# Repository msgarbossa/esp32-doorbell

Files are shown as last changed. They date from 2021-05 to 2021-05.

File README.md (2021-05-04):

# ESP32 doorbell

## Description

My doorbell chime stopped working so I made my own smart doorbell.

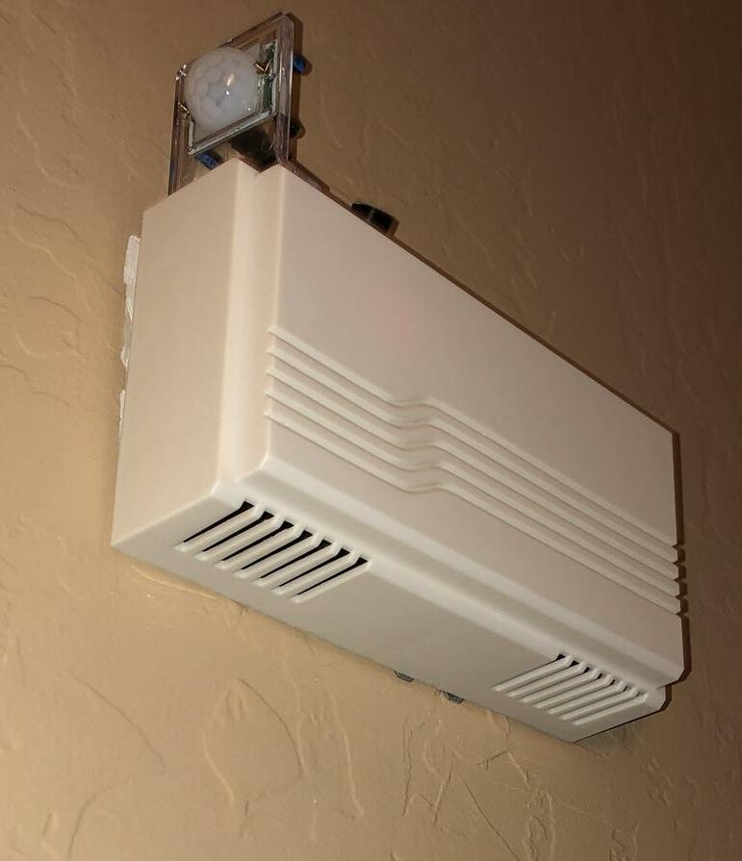
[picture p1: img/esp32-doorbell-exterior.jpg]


- Drop-in replacement for existing doorbell
- Uses original low-tech button
- NTP is used to set time and allow for Do-not-Disturb hours
- In addition to playing a sound when the doorbell button is pressed, an MQTT message is published
- A PIR motion sensor also sends MQTT messages
- Node-RED subscribes to the MQTT topic and sends a message using Slack when the doorbell button is pressed
- Node-RED publishes Prometheus metrics so events can be graphed in Grafana

## Parts

- [ESP32 devkit - 30 pin, integrated antenna](https://www.aliexpress.com/item/1005001267643044.html)
- [passive piezo buzzer](https://www.aliexpress.com/item/4001317667682.html) or anything to make noise
- [HC-SR501 Infrared PIR Motion Sensor](https://www.aliexpress.com/item/32731348914.html)

## Code

As my first major rewrite of my doorbell, I originally changed everything to attach interrupts to the digital input pins for the doorbell button and motion sensor.  Unfortunately, this was not reliable and caused too many false alarms.  I'm pretty sure the long telephone wire that runs from the doorbell to the door was picking up elecrical noise and acting like a large antenna.  I may eventually purchase some octocouplers and try this out again.  The working code is back to a more traditional setup of polling and reading the digital inputs.  Going with interrupts would also allow deep sleep to be used.

## Assembly

The inside is a bit ugly.  I gutted the box with a dremel tool and a cutoff wheel.  I removed the old transformer from the wall and replaced it with a standard receptacle.  The small USB adapter has the port on the side, allowing the existing doorbell cover to fit over all of the parts.  I was considering 3D printing a 2-gang electrical box cover to completely replace the old doorbell case, but I'd have some paint to touch up and I just started learning FreeCAD and wanted to start small.

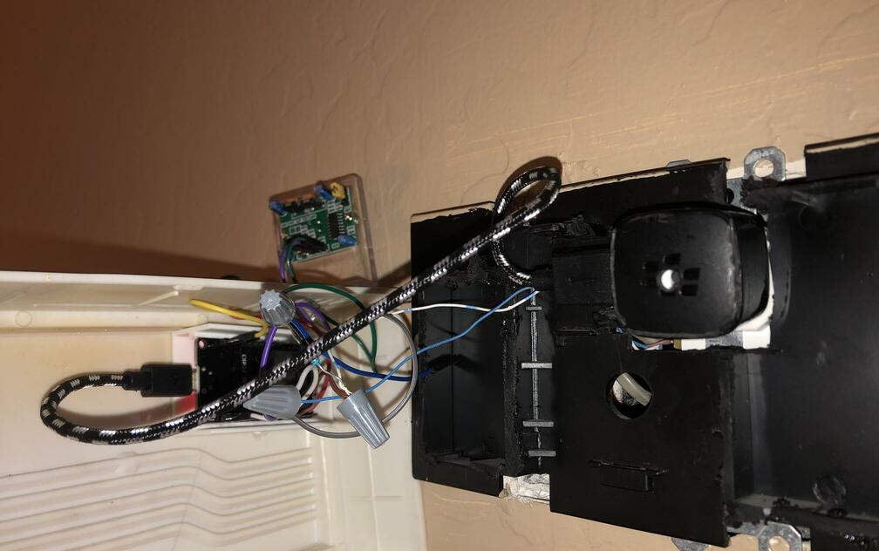
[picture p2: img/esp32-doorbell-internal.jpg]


The FreeCAD and STL files are in the *case* folder.  The rails perfectly fit the 30-pin ESP32 w/ integrated antenna and the 38-pin ESP32 w/ external antenna.  This was my first test-print, but it helped with the assembly to quickly hot-glue the ESP32 holder to the inside of the old doorbell case.

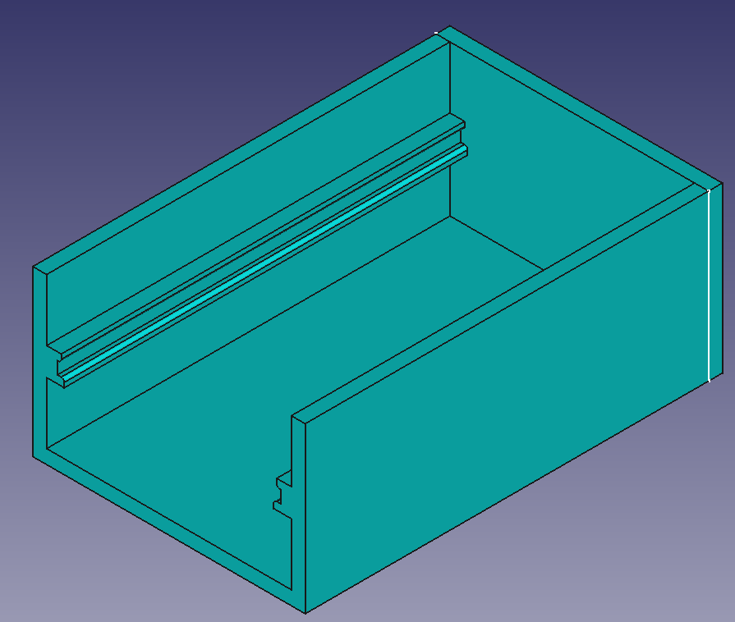
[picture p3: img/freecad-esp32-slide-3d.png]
3d-case-model


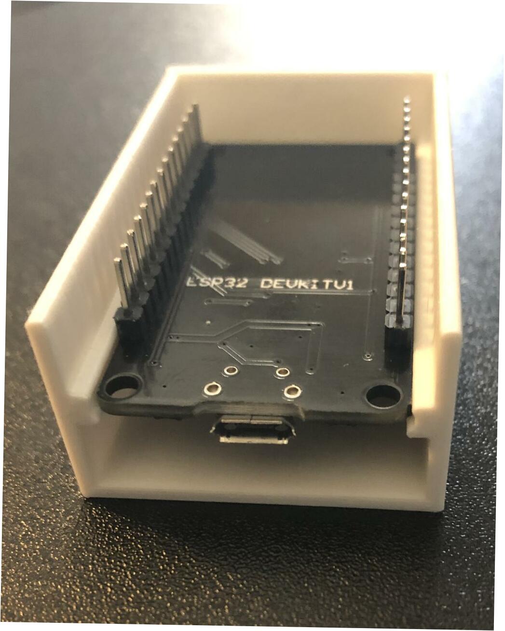
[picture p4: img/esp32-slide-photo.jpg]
project photo


## Diagram

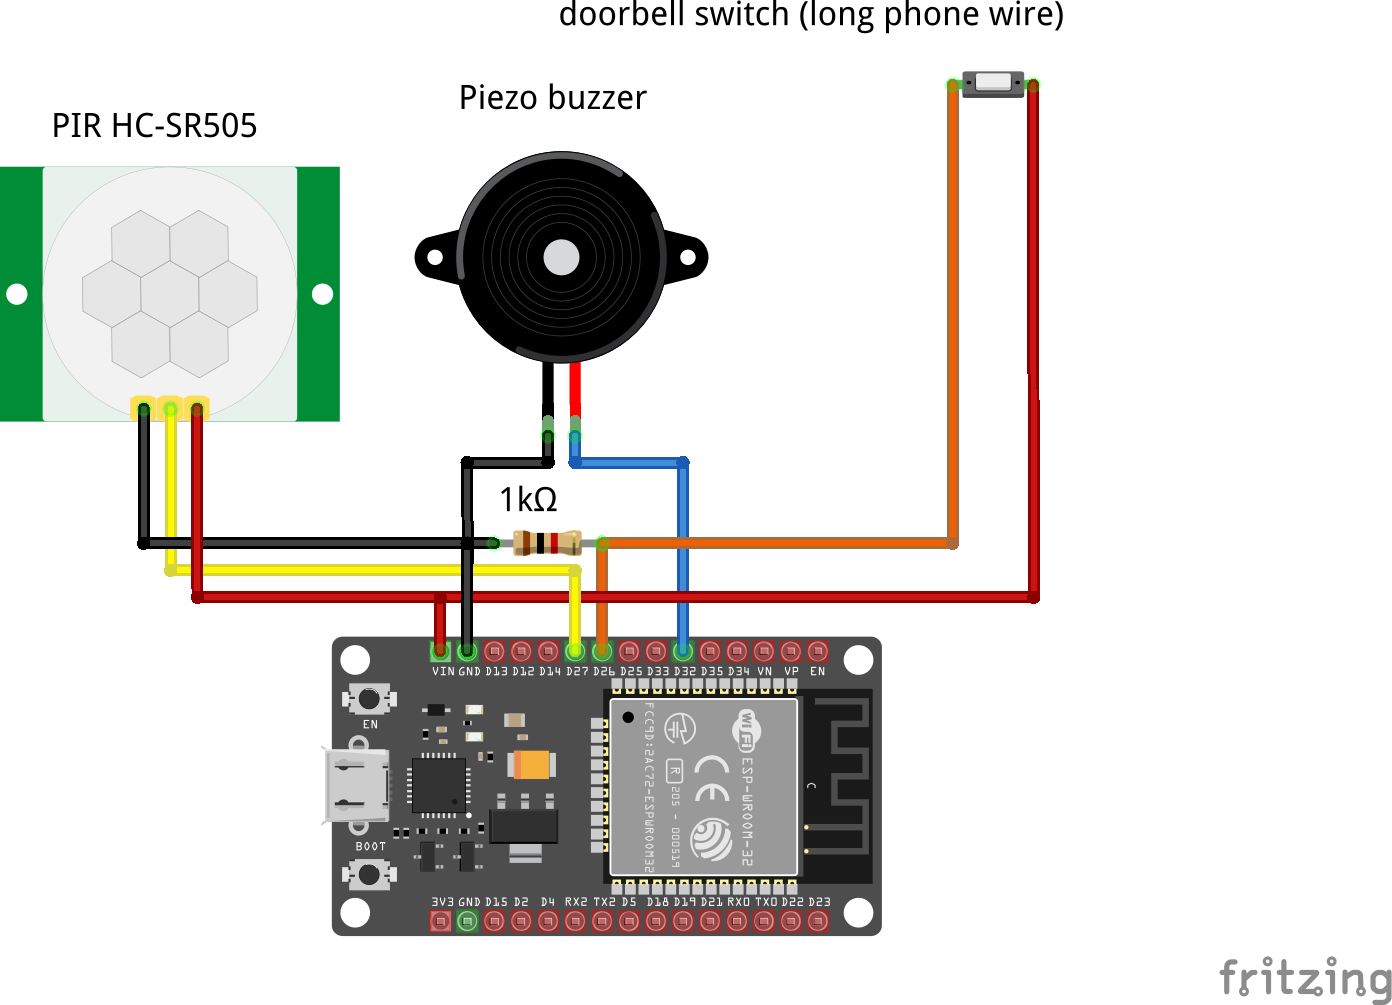
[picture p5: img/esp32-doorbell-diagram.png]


When developing this, I swapped the buzzer out for an LED with the same code.

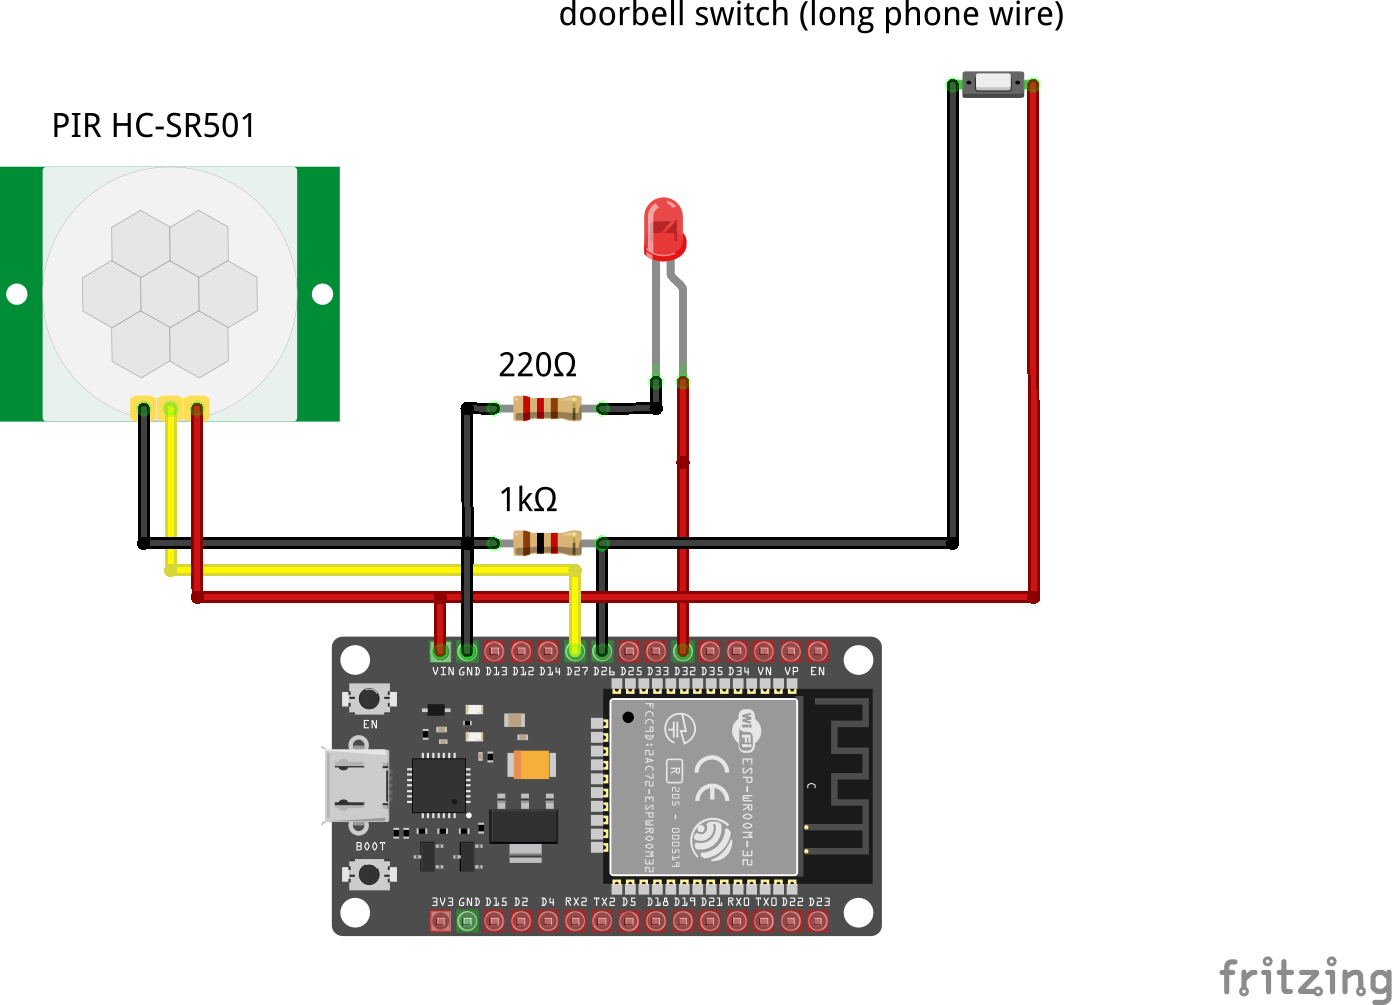
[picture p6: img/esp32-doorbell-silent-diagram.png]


## Node-RED

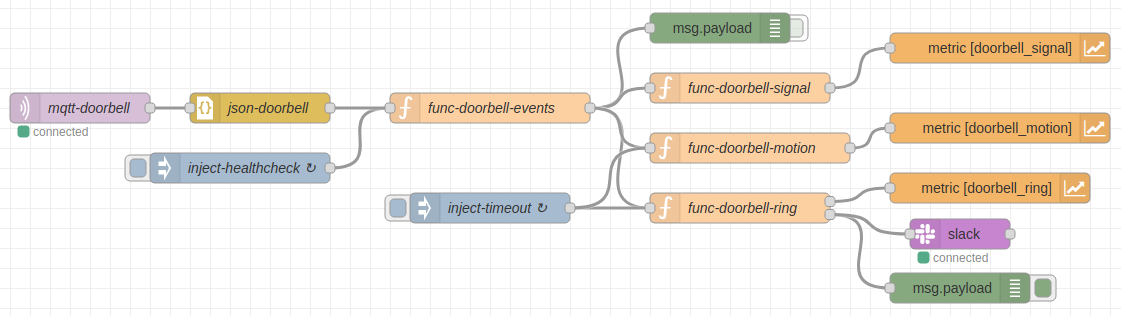
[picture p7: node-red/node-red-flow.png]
Node-RED flow

[JSON for above flow](node-red/flow.json)

The beginning of the flow starts out with Node-RED listening on the MQTT topic for messages.  The messages get converted from JSON to payload objects.  Whenever an MQTT message is received, a timestamp is recorded in the func-doorbell-events node.

The "inject healthcheck" node periodically sends a message that is compared to the last MQTT timestamp.  If no MQTT messages have been recieved for a while, the flow is marked offline and a new message is returned to zero out the Prometheus metrics at the end of the flow.

The "inject timeout" handles resetting the motion and doorbell Prometheus metrics back to zero after an alert, but ensures the value stays at "1" long enough for Prometheus to scrape the exporter.

The Prometheus data shown below is at \<node_red_url\>:1880/metrics.

```
# HELP doorbell_signal doorbell signal
# TYPE doorbell_signal gauge
doorbell_signal -59

# HELP doorbell_ring doorbell ring
# TYPE doorbell_ring gauge
doorbell_ring 0

# HELP doorbell_motion doorbell motion
# TYPE doorbell_motion gauge
doorbell_motion 0
```

The func-doorbell-ring node also sends a message to Slack.

Below is an example graph in Grafana.

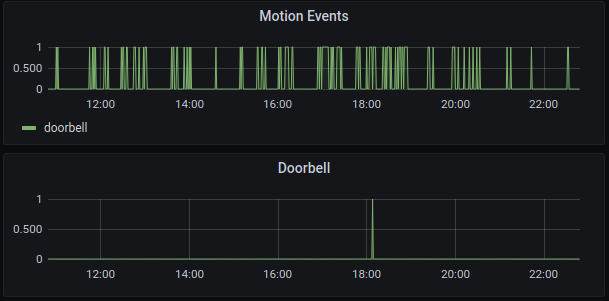
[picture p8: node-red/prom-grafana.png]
Prometheus - Grafana


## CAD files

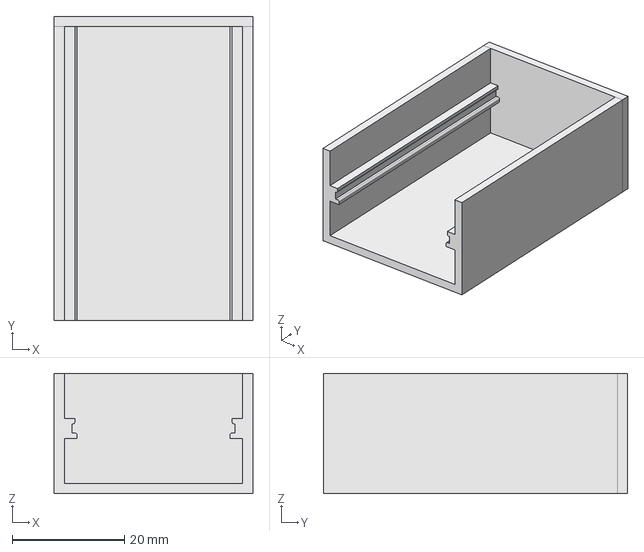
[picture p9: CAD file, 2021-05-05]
case/esp32-slide-case.step
35.4 x 54.2 x 21.4 mm

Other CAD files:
case/esp32-slide-case.stl

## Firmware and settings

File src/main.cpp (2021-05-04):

#include <Arduino.h>
#include <WiFi.h>
extern "C" {
  #include "freertos/FreeRTOS.h"
  #include "freertos/timers.h"
}
#include <AsyncMqttClient.h>
#include <time.h>

#include "config/config.h"
#include "functions/wifi-connection.h"
#include "functions/ota.h"
#include "functions/doorbell.h"
#include "functions/mqtt.h"
#include "functions/motion.h"

// #include "tasks/motion-detect.h"

#ifdef __arm__
// should use uinstd.h to define sbrk but Due causes a conflict
extern "C" char* sbrk(int incr);
#else  // __ARM__
extern char *__brkval;
#endif  // __arm__

// Variables to hold metric/sensor values
int doorbellStatus = 0;
bool doorbellChanged = false;
int motionState = 0;
bool motionChanged = false;
unsigned long prevMillisMotion = 0; // Stores last motionState = 1
unsigned long prevMillisDoorbell = 0;  // Stores last doorbellStatus = 1
unsigned long prevMillisMQTT = 0;   // Stores last time sensor was published
unsigned long prevNtpMillis = 0;   // Stores last time NTP was updated

// Variables to hold sensor info
int8_t wifi_strength;
IPAddress ip;
time_t now;
struct tm * timeinfo;
char TimeString[9]; // 8 digits plus the null char (00:00:00)


// Temperature MQTT Topics
#define MQTT_PUB_TOPIC "home/" DEVICE_NAME "/metrics"
#define MQTT_SUB_TOPIC "home/" DEVICE_NAME "/cmd"

AsyncMqttClient mqttClient;
TimerHandle_t mqttReconnectTimer;
TimerHandle_t wifiReconnectTimer;
// TimerHandle_t checkDoorTimer;
// TimerHandle_t checkLeakTimer;

const char* wl_status_to_string(int status) {
  switch (status) {
    case WL_NO_SHIELD: return "WL_NO_SHIELD";
    case WL_IDLE_STATUS: return "WL_IDLE_STATUS";
    case WL_NO_SSID_AVAIL: return "WL_NO_SSID_AVAIL";
    case WL_SCAN_COMPLETED: return "WL_SCAN_COMPLETED";
    case WL_CONNECTED: return "WL_CONNECTED";
    case WL_CONNECT_FAILED: return "WL_CONNECT_FAILED";
    case WL_CONNECTION_LOST: return "WL_CONNECTION_LOST";
    case WL_DISCONNECTED: return "WL_DISCONNECTED";
    default: return "UNKNOWN";
  }
}

void connectToWifi() {
  btStop(); // turn off bluetooth
  Serial.println("Connecting to Wi-Fi...");
  WiFi.begin(WIFI_NETWORK, WIFI_PASSWORD);
}

void connectToMqtt() {
  Serial.println("Connecting to MQTT...");
  mqttClient.connect();
}

void WiFiEvent(WiFiEvent_t event) {
  Serial.printf("[WiFi-event] event: %d\n", event);
  switch(event) {
    case SYSTEM_EVENT_STA_GOT_IP:
      Serial.println("WiFi connected");
      Serial.println("IP address: ");
      ip = WiFi.localIP();
      Serial.println(WiFi.localIP());
      connectToMqtt();
      break;
    case SYSTEM_EVENT_STA_DISCONNECTED:
      Serial.println("WiFi lost connection");
      xTimerStop(mqttReconnectTimer, 0); // ensure we don't reconnect to MQTT while reconnecting to Wi-Fi
      xTimerStart(wifiReconnectTimer, 0);
      break;
    default:
      break;
  }
}

void updateWiFiSignalStrength() {
  if(WiFi.isConnected()) {
    //serial_println(F("[WIFI] Updating signal strength..."));
    wifi_strength = WiFi.RSSI();
    // Serial.print("[WIFI] signal strength: ");
    // Serial.println(wifi_strength);
  }
}

void onMqttConnect(bool sessionPresent) {
  Serial.println("Connected to MQTT.");
  Serial.print("Session present: ");
  Serial.println(sessionPresent);
  uint16_t packetIdSub = mqttClient.subscribe(MQTT_SUB_TOPIC, 2);
  Serial.print("Subscribing at QoS 2, packetId: ");
  Serial.println(packetIdSub);
}

void onMqttDisconnect(AsyncMqttClientDisconnectReason reason) {
  Serial.println("Disconnected from MQTT.");
  if (WiFi.isConnected()) {
    xTimerStart(mqttReconnectTimer, 0);
  }
}

void onMqttPublish(uint16_t packetId) {
  Serial.print("Publish acknowledged.");
  Serial.print("  packetId: ");
  Serial.println(packetId);
}

void sendMqttUpdate() {
  char msg[58];  // variable for MQTT payload
  sprintf(msg, "{\"s\":\"%d\",\"d\":\"%d\",\"m\":\"%d\"}", wifi_strength, doorbellStatus, motionState);
  uint16_t packetIdPub1 = mqttClient.publish(MQTT_PUB_TOPIC, 0, false, msg);
  Serial.printf("[MQTT] Publishing on topic %s at QoS 1, packetId: %i\n", MQTT_PUB_TOPIC, packetIdPub1);
  Serial.println(msg);
}

void onMqttSubscribe(uint16_t packetId, uint8_t qos) {
  Serial.println("Subscribe acknowledged.");
  Serial.print("  packetId: ");
  Serial.println(packetId);
  Serial.print("  qos: ");
  Serial.println(qos);
}
void onMqttUnsubscribe(uint16_t packetId) {
  Serial.println("Unsubscribe acknowledged.");
  Serial.print("  packetId: ");
  Serial.println(packetId);
}

void onMqttMessage(char* topic, char* payload, AsyncMqttClientMessageProperties properties, size_t len, size_t index, size_t total) {
  Serial.println("Publish received.");
  Serial.print("  topic: ");
  Serial.println(topic);
  Serial.print("  qos: ");
  Serial.println(properties.qos);
  Serial.print("  dup: ");
  Serial.println(properties.dup);
  Serial.print("  retain: ");
  Serial.println(properties.retain);
  Serial.print("  len: ");
  Serial.println(len);
  Serial.print("  index: ");
  Serial.println(index);
  Serial.print("  total: ");
  Serial.println(total);

  char s_payload[len + 1];
  String payload2 = "";
  if (len < 20) {
    Serial.print("  payload: ");
    s_payload[len] = '\0';
    strncpy(s_payload, payload, len);
    Serial.println(s_payload);
    payload2 = s_payload;
  } else {
    Serial.println(" payload len>20");
  }
  if (payload2 == "blink") {
    blink_now();
    prevMillisMQTT = 0;
  }
  if (payload2 == "toggle") {
    play_sound();
  }

}


void fetchTimeFromNTP() {
  if(!WiFi.isConnected()) {
      return;
  }
  Serial.println("[NTP] Updating...");
  // init and get the time
  configTime(NTP_GMT_OFFSET_SECONDS, NTP_DAYLIGHT_OFFSET_SECONDS, NTP_SERVER);
  Serial.println("[NTP] Done");
}

void setup() {
  Serial.begin(115200);
  Serial.println();

  pinMode(LED_PIN, OUTPUT);  // Initialize the LED pin as an output

  // sound setup
  setup_sound();

  mqttReconnectTimer = xTimerCreate("mqttTimer", pdMS_TO_TICKS(2000), pdFALSE, (void*)0, reinterpret_cast<TimerCallbackFunction_t>(connectToMqtt));
  wifiReconnectTimer = xTimerCreate("wifiTimer", pdMS_TO_TICKS(2000), pdFALSE, (void*)0, reinterpret_cast<TimerCallbackFunction_t>(connectToWifi));

  WiFi.onEvent(WiFiEvent);

  mqttClient.onConnect(onMqttConnect);
  mqttClient.onDisconnect(onMqttDisconnect);
  mqttClient.onSubscribe(onMqttSubscribe);
  mqttClient.onUnsubscribe(onMqttUnsubscribe);
  mqttClient.onMessage(onMqttMessage);
  mqttClient.onPublish(onMqttPublish);
  mqttClient.setServer(MQTT_HOST, MQTT_PORT);
  mqttClient.setCredentials(MQTT_USER, MQTT_PASSWORD);
  connectToWifi();
  setupOTA();
  fetchTimeFromNTP();

  setupDoorbell();
  xTaskCreate(
      doorbellMonitor,    // Function
      "Doorbell Status",  // Task name
      5000,                  // Stack size (bytes)
      NULL,                   // Parameter
      3,                      // Task priority
      NULL                    // Task handle
    );

  #if MOTION_ENABLED == true
      motionSetup();
      xTaskCreate(
        motionMonitor,    // Function
        "Motion Status",  // Task name
        5000,                  // Stack size (bytes)
        NULL,                   // Parameter
        4,                      // Task priority
        NULL                    // Task handle
    );
  #endif
  
  vTaskDelay(1000 / portTICK_PERIOD_MS);
}

void printTime() {
    time(&now);
    timeinfo = localtime(&now);
    sprintf(TimeString, "%02d:%02d:%02d", timeinfo->tm_hour, timeinfo->tm_min, timeinfo->tm_sec);
    Serial.print("[TIME] ");
    Serial.println(TimeString);
}

void loop() {
  ArduinoOTA.handle();

  unsigned long currentMillis = millis();
  bool forceMqttUpdate = false;

  // update NTP every NTP_UPDATE_INTERVAL_MS millis
  if (currentMillis - prevNtpMillis >= NTP_UPDATE_INTERVAL_MS) {
    // Save the last time NTP was updated
    prevNtpMillis = currentMillis;
    fetchTimeFromNTP();
  }

  // motion reset
  if(motionState == 1 && (currentMillis - prevMillisMotion > (MOTION_OFF_SEC*1000))) {
    Serial.println("[MOTION] reset");
    motionState = 0;
    printTime();
  }

  // motion alert
  if(motionState == 1 && motionChanged && (currentMillis - prevMillisMotion < (MOTION_OFF_SEC*1000))) {
    Serial.println("[MOTION] ACTIVE");
    printTime();
    forceMqttUpdate = true;
  }

  // doorbell reset
  if(doorbellStatus == 1 && (currentMillis - prevMillisDoorbell > (DOORBELL_RESET_SEC*1000))) {
    Serial.println("[DOORBELL] reset");
    doorbellStatus = 0;
    printTime();
  }

  // doorbell alert
  if(doorbellStatus == 1 && doorbellChanged && (currentMillis - prevMillisDoorbell < (DOORBELL_RESET_SEC*1000))) {
    Serial.println("[DOORBELL] ring!");
    doorbellSound(); // takes into account Do Not Disturb
    blink_now();
    printTime();
    forceMqttUpdate = true;
  }

  // publish a new MQTT message MQTT_PUBLISH_SEC seconds
  if ((currentMillis - prevMillisMQTT >= (MQTT_PUBLISH_SEC * 1000)) || (forceMqttUpdate == true)) {
    // Save the last time a new reading was published
    prevMillisMQTT = currentMillis;
    doorbellChanged = false;
    motionChanged = false;
    blink_now();
    updateWiFiSignalStrength();
    sendMqttUpdate();
  }
}

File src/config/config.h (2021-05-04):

#ifndef CONFIG
#define CONFIG

#define DEVICE_NAME "doorbell"

// WiFi
#define WIFI_NETWORK "SSID"
#define WIFI_PASSWORD "PW"
#define WIFI_TIMEOUT 20000 // 20 seconds
#define WIFI_RECOVER_TIME_MS 1000 // (1-20 seconds)

// MQTT
#define MQTT_HOST IPAddress(X, X, X, X)
#define MQTT_PORT 1883
#define MQTT_USER "user"
#define MQTT_PASSWORD "password"
#define MQTT_CONNECT_DELAY 200
#define MQTT_CONNECT_TIMEOUT 10000 // 10 seconds
#define MQTT_PUBLISH_SEC 300 // 5 minutes

#define LED_PIN 2 // for activity blink
#define SOUND_PIN 32 // for alerts

// NTP
#define NTP_SERVER "10.10.1.1"
#define NTP_GMT_OFFSET_SECONDS -25200
#define NTP_DAYLIGHT_OFFSET_SECONDS 0
#define NTP_UPDATE_INTERVAL_MS 3600000

// Doorbell
#define DOORBELL_BUTTON_PIN 26
#define DOORBELL_DND_ENABLED true  // Do Not Disturb, requires NTP_ENABLED if true
#define DOORBELL_DND_START_HR 20  // silences hr >= this number
#define DOORBELL_DND_END_HR 7  // silences hr <= this number
#define DOORBELL_RESET_SEC 3  // Minimum time between ring messages (10)

// Motion sensor configurations
#define MOTION_ENABLED true
#define MOTION_PIN 27
#define MOTION_OFF_SEC 10  // Should be long enough for Prometheus to scrape (65s)

#endif
